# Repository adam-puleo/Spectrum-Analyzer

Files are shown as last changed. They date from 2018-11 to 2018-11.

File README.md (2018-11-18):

# Spectrum-Analyzer
Uses the MSGEQ7 chips and a NeoPixel matrix to display frequency volumes using a Particle Photon.

This project uses two MSGEQ7 chips (COM-10468 on SparkFun.com) to analyze sound frequencies. One chip for the left, and the other chip for the right channel. Input is via a 3.5mm audio jack. The frequency volumes, and average volume is displayed with a NeoPixel matrix (COM-13304 on SparkFun.com). Data is processed using Particle's Photon (particle.io).

The Photon uses 3.3 volts on its analog and digital pins. The MSGEQ7 and NeoPixels are 5 volts. A SN74HCT125N is used to drive the inputs on the MSGEQ7 and NeoPixel from the Photon. To read the MSGEQ7s output a voltage divider circuit is used. The MSGEQ7 seems to output 4.8 volts when a frequency is at maximum volume thus a 1.5k ohm resistor is used. Pin eight of the SN74HCT125N is used to drive the NeoPixel matrix. Gate B, output pin 6, of the SN74HCT125N is not used.

The msgeq7, spectrum_display, and neopixelmatrix libraries have been published to Particle's public libraries. Thus when you compile the code Particle will automatically link with the libraries. The 'Eagle/Audio Lights' directory contains the schematic in Autodesk's EAGLE program.

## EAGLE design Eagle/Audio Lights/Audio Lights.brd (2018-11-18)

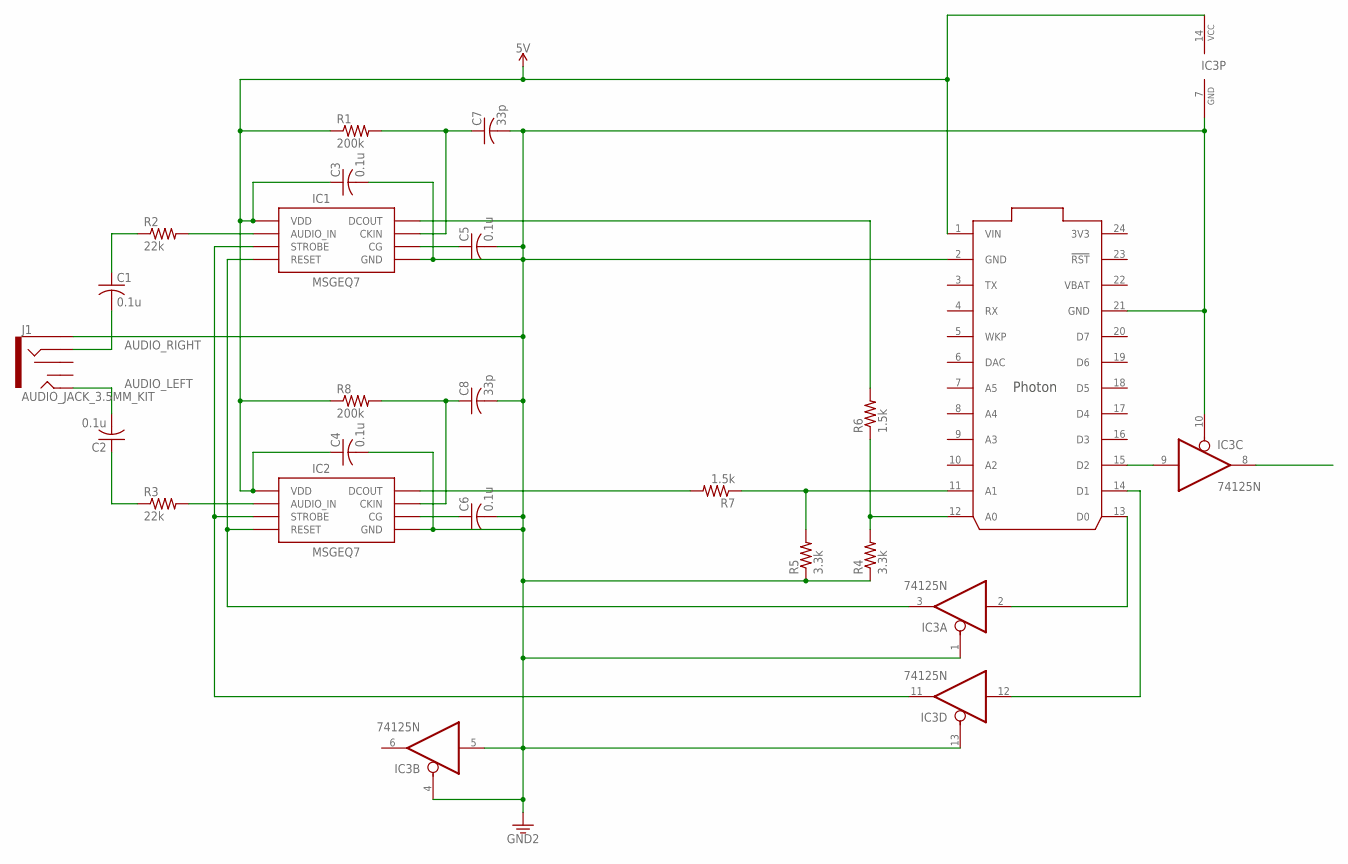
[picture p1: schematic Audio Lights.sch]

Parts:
C1, C2, C3, C4, C5, C6: 0.1u; C025-024X044
C7, C8: 33p; C050-045X075
IC1, IC2: MSGEQ7P; DIP08
IC3: 74125N; DIL14
J1: AUDIO_JACK_3.5MM_KIT; AUDIO-JACK-KIT
R1, R8: 200k; 0204/7
R2, R3: 22k; 0204/7
R4, R5: 3.3k; 0204/5
R6, R7: 1.5k; 0204/5
U$1: PHOTON_WITH_HEADERS; PHOTON

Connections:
3V3: U$1.24 (3V3)
5V: C3.1, C4.1, IC1.1 (VDD), IC2.1 (VDD), IC3.14 (VCC), R1.1, R8.1, U$1.1 (VIN)
AGND_LEFT: C6.1, IC2.6 (CG)
AGND_RIGHT: C5.1, IC1.6 (CG)
AUDIO_IN_LEFT: IC2.5 (AUDIO_IN), R3.2
AUDIO_IN_RIGHT: IC1.5 (AUDIO_IN), R2.2
AUDIO_LEFT: C2.2, J1.TIP
AUDIO_RIGHT: C1.2, J1.RING
CLK_LEFT: C8.1, IC2.8 (CKIN), R8.2
CLK_RIGHT: C7.1, IC1.8 (CKIN), R1.2
DOUT_LEFT3V3: R5.2, R7.1, U$1.11 (A1)
DOUT_LEFT5V: IC2.3 (DCOUT), R7.2
DOUT_RIGHT3V3: R4.2, R6.1, U$1.12 (A0)
DOUT_RIGHT5V: IC1.3 (DCOUT), R6.2
GND: C3.2, C4.2, C5.2, C6.2, C7.2, C8.2, IC1.2 (GND), IC2.2 (GND), IC3.1 (OE), IC3.4 (OE), IC3.5 (I), IC3.7 (GND), IC3.10 (OE), IC3.13 (OE), J1.SLEEVE, R4.1, R5.1, U$1.2 (GND), U$1.21 (GND)
LED_3.3V: IC3.9 (I), U$1.15 (D2)
LED_5V: IC3.8 (O)
unnamed: C2.1, R3.1
unnamed: C1.1, R2.1
RESET_3.3V: IC3.2 (I), U$1.13 (D0)
RESET_5V: IC1.7 (RESET), IC2.7 (RESET), IC3.3 (O)
STROBE_3.3V: IC3.12 (I), U$1.14 (D1)
STROBE_5V: IC1.4 (STROBE), IC2.4 (STROBE), IC3.11 (O)
VBAT: U$1.22 (VBAT)

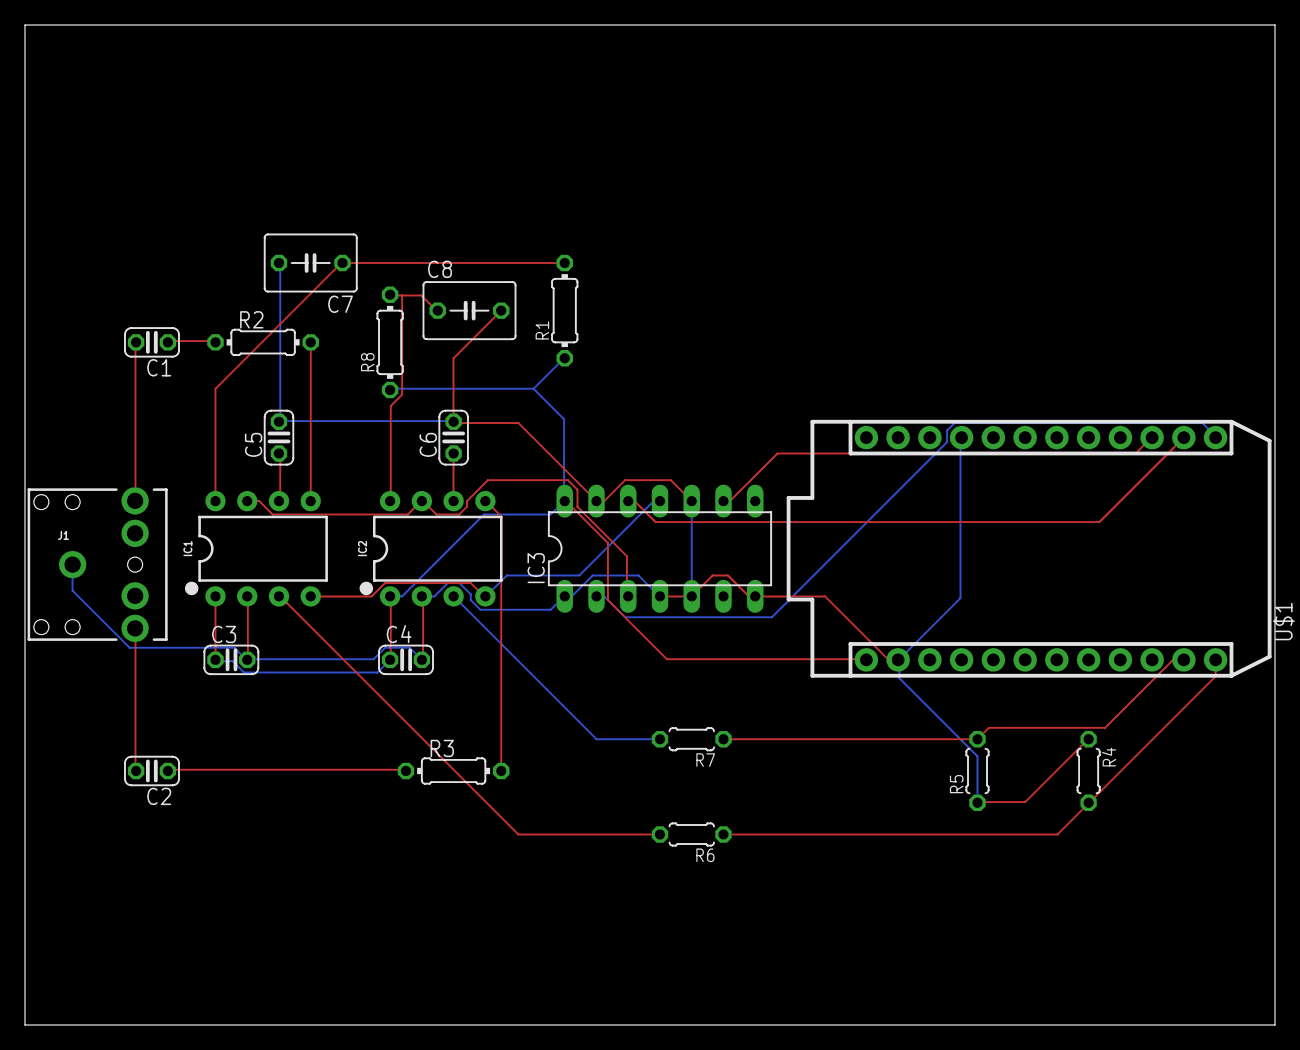
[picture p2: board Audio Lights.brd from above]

Board: 2 copper layers, 100.0 x 80.0 mm, 21 parts (0 on the bottom side), 21 nets.

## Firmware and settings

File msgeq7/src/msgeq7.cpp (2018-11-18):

/* msgeq7 library by Adam Puleo
 */

#include "msgeq7.h"

void Msgeq7::init(uint8_t resetPin, uint8_t strobePin) {
  // Setup private variables
  this->resetPin = resetPin;
  this->strobePin = strobePin;
}

/**
 * Constructors
 */
 Msgeq7::Msgeq7(uint8_t resetPin, uint8_t strobePin, uint8_t analogPin) {
   this->numChannels = 1;
   this->analogPins[0] = analogPin;

   init(resetPin, strobePin);
 }

 Msgeq7::Msgeq7(uint8_t resetPin, uint8_t strobePin, uint8_t analogPin, uint8_t analogPin2) {
   this->numChannels = 2;
   this->analogPins[0] = analogPin;
   this->analogPins[1] = analogPin2;

   init(resetPin, strobePin);
 }

 Msgeq7::Msgeq7(uint8_t resetPin, uint8_t strobePin, uint8_t analogPin, uint8_t analogPin2, uint8_t analogPin3) {
   this->numChannels = 3;
   this->analogPins[0] = analogPin;
   this->analogPins[1] = analogPin2;
   this->analogPins[2] = analogPin3;

   init(resetPin, strobePin);
 }

 Msgeq7::Msgeq7(uint8_t resetPin, uint8_t strobePin, uint8_t analogPin, uint8_t analogPin2, uint8_t analogPin3, uint8_t analogPin4) {
   this->numChannels = 4;
   this->analogPins[0] = analogPin;
   this->analogPins[1] = analogPin2;
   this->analogPins[2] = analogPin3;
   this->analogPins[3] = analogPin4;

   init(resetPin, strobePin);
 }

/**
 * Initialize hardware
 */
void Msgeq7::begin()
{
    // Initialize the Photon pins
    pinMode(this->resetPin, OUTPUT);
    pinMode(this->strobePin, OUTPUT);
    for (uint8_t channel = 0; channel < this->numChannels; channel++) {
      pinMode(this->analogPins[channel], AN_INPUT);
    }

    // Setup the MSGEQ7
    digitalWrite(this->resetPin, LOW);
    digitalWrite(this->strobePin, LOW);
}

void Msgeq7::read() {
  // With every read of the MSGEQ7 the output decays by 10%. Thus on every read
  // send a reset.
  digitalWrite(this->resetPin, HIGH); // tr - Needs to stay high for at least 100ns.
  digitalWrite(this->strobePin, LOW); // ts - Needs to stay high for at least 18us.
  delayMicroseconds(18);
  digitalWrite(this->resetPin, LOW);
  digitalWrite(this->strobePin, HIGH); // tss - One period must be at least 72us. So at this point the strobe pin needs to stay high at lease another 54us.
  delayMicroseconds(54);

  // read all 7 frequencies
	// 63Hz, 160Hz, 400Hz, 1kHz, 2.5kHz, 6.25KHz, 16kHz
	for (uint8_t freq = FREQ63; freq < FREQ16k + 1; freq++) {
		// trigger next value
		digitalWrite(this->strobePin, LOW);

		// allow the output to settle - 'to' 36us min
		delayMicroseconds(36);

    for (uint8_t channel = 0; channel < this->numChannels; channel++) {
      this->frequencies[channel][freq] = analogRead(this->analogPins[channel]);
    };

    digitalWrite(this->strobePin, HIGH);
    /* Strobe to strobe delay (tss) is 72us min. Could probably shorten this
       as analogRead takes awhile. I'm not sure how long though.
    */
    delayMicroseconds(36);
  };
  digitalWrite(this->strobePin, LOW);

  // Recalculate the volume for each channel.
  for (uint8_t channel = 0; channel < this->numChannels; channel++) {
    uint32_t sum = 0;
    for (uint8_t freq = FREQ63; freq < FREQ16k + 1; freq++) {
      sum += this->frequencies[channel][freq];
    }
    this->volume[channel] = sum / (FREQ16k + 1);
  }
};

// Return the value read by the Photon for the frequency for the requested IC.
uint16_t Msgeq7::get(const uint8_t channel, const FREQS freq) {
  if (channel < this->numChannels && freq <= FREQ16k) {
    return this->frequencies[channel][freq];
  } else {
    return 0;
  }
}

// Return the channel's volume. The volume is calculated in the read function.
uint16_t Msgeq7::get_volume(const uint8_t channel) {
  if (channel < this->numChannels) {
    return this->volume[channel];
  } else {
    return 0;
  }
}

/**
 * Destructor
 */
Msgeq7::~Msgeq7()
{
    // Set the digital pins back to input.
    pinMode(this->resetPin, INPUT);
    pinMode(this->strobePin, INPUT);

    // The analoog pins were already set to input, nothing to do for them.
}

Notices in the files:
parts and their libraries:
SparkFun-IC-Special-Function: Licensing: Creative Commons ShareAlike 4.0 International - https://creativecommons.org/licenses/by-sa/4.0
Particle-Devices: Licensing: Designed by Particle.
